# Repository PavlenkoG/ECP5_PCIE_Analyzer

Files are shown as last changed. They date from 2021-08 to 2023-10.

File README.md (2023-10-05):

# ECP5_PCIE_Analyzer
The main idea of this project is the evaluation of the possibility of using the PCS-Block of ECP5UMG FPGA for PCI-Express protocol analysis.
The PCS Block can deserialize physical PCI-Express signals and decode 8b10b. <p>
Deserialized data can be used to analyze protocol traffic, detecting errors and so on.<p>
The first implementation involves an adapter print to connect PCI-Express lanes to PCS-Block in FPGA and an evaluation board with ECP5UM(G).<p>
The adapter print should be connected to the eval. board through VERSA Expansion headers and SMA-Cables.

https://www.latticesemi.com/products/developmentboardsandkits/ecp5evaluationboard
# VERSA Expansion Headers
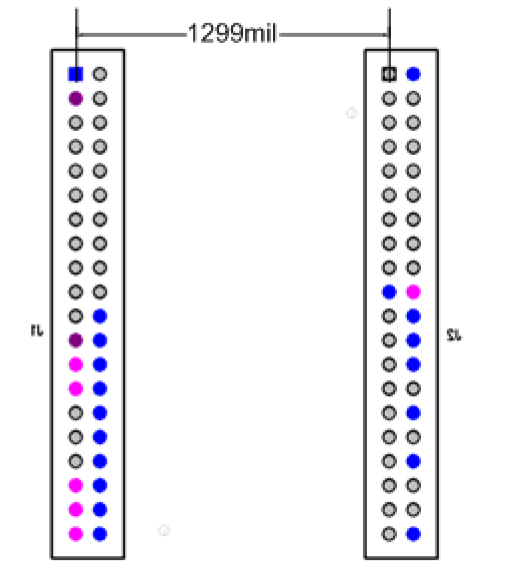
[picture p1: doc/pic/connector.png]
sch

# Eval Board top view
Block Schema

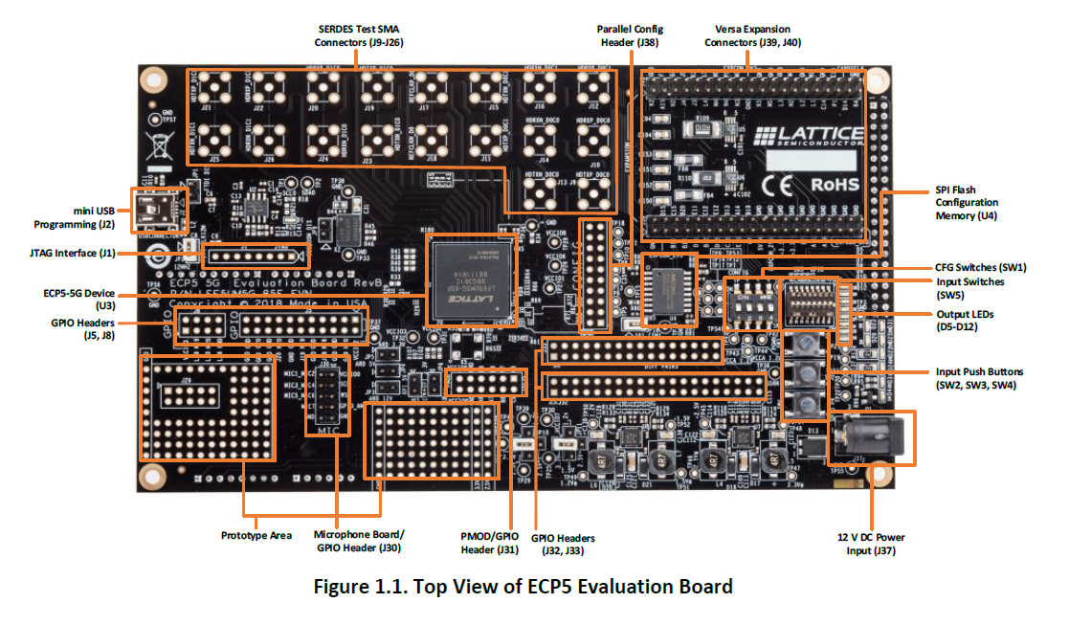
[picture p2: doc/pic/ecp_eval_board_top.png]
Eval Board Top


# Eval Board bottom view
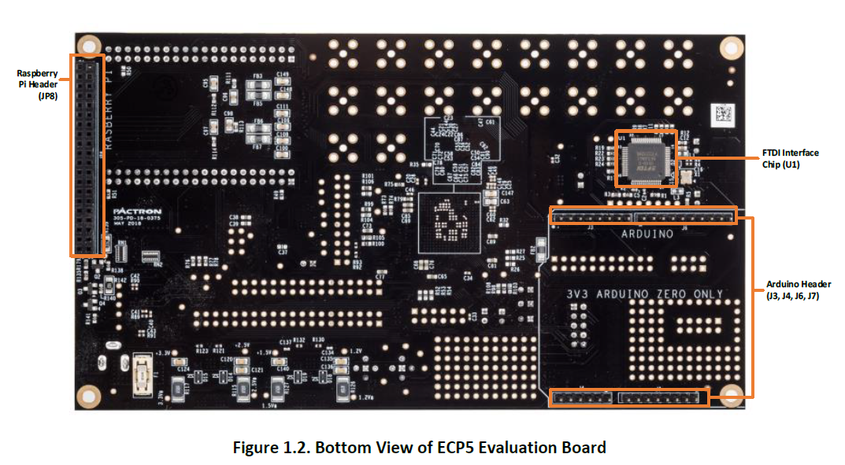
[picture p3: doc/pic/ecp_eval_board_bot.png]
Eval Board Bottom


# PCB

Preparing for applying solder paste
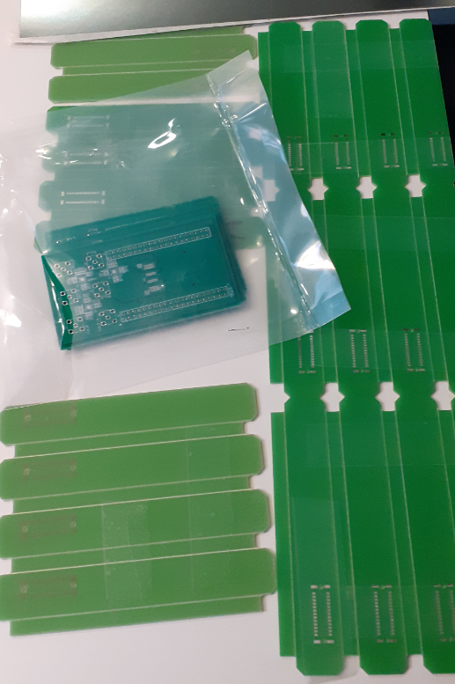
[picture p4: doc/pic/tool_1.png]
tool_1


Mounting of SMT Stencil
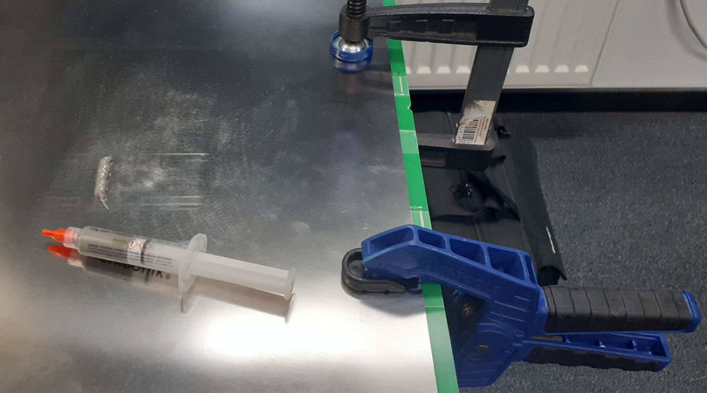
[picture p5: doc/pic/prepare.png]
mounting of SMT Stencil


Applying solder paste
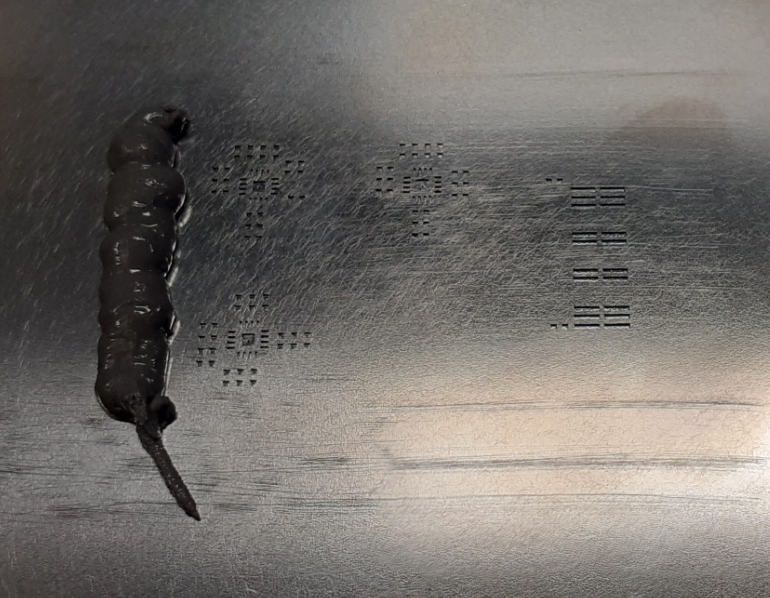
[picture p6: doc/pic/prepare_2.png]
applying solder paste


PCB
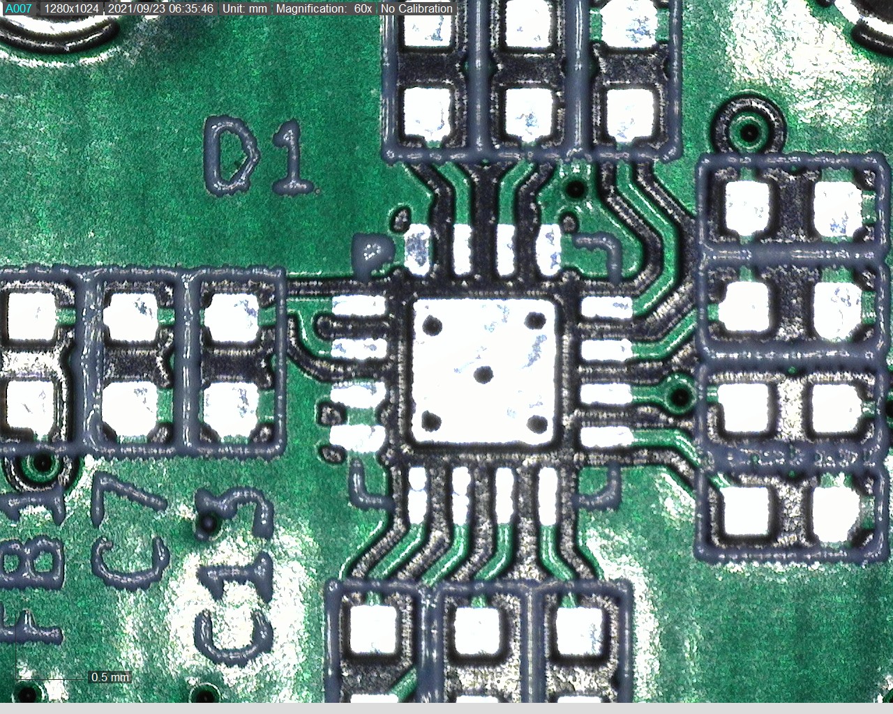
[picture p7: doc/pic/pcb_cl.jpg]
PCB


PCB with solder paste
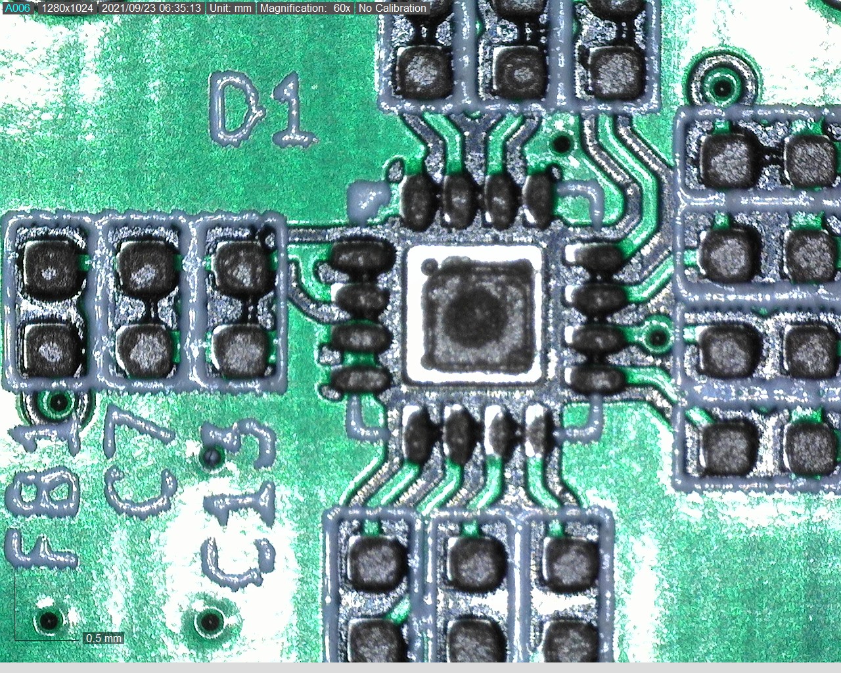
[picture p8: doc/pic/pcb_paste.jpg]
PCB with paste


Mounted PCB
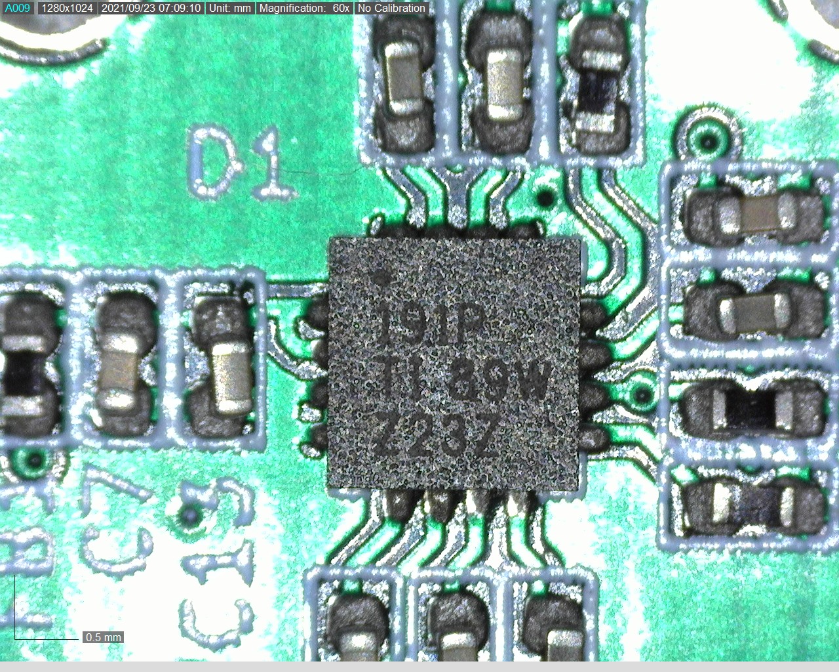
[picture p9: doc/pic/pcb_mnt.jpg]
Mounted PCB


# Python script usage

## record data (on raspberry pi)

```
pi@raspberrypi:~/github/ECP5_PCIE_Analyzer/py_script $ python3 analyzer.py
['analyzer.py']
file removed
Time:  11.82167429399999 s
```

## analyze data

copy data to local
```
scp -r pi@192.168.178.29:~/github/ECP5_PCIE_Analyzer/py_script/*.csv .
```

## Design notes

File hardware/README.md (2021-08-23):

## Impedance calculation JLCPCB

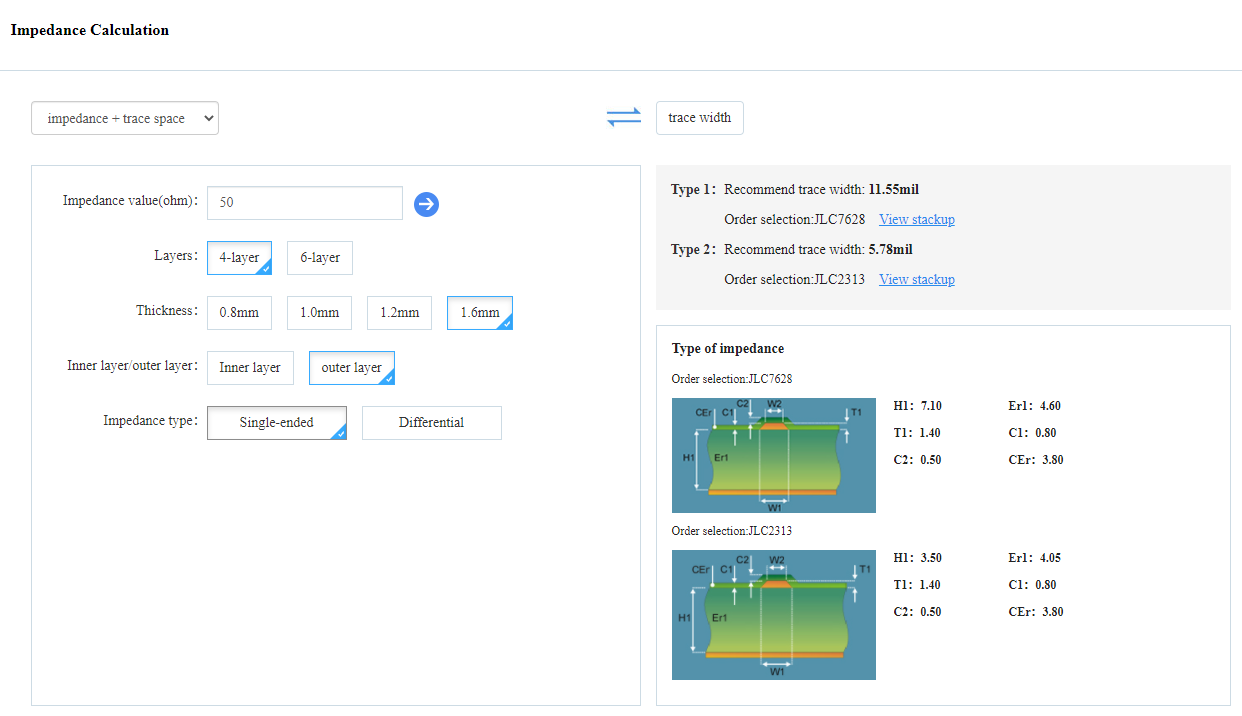
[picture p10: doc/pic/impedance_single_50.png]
impedance 50 Ohm single

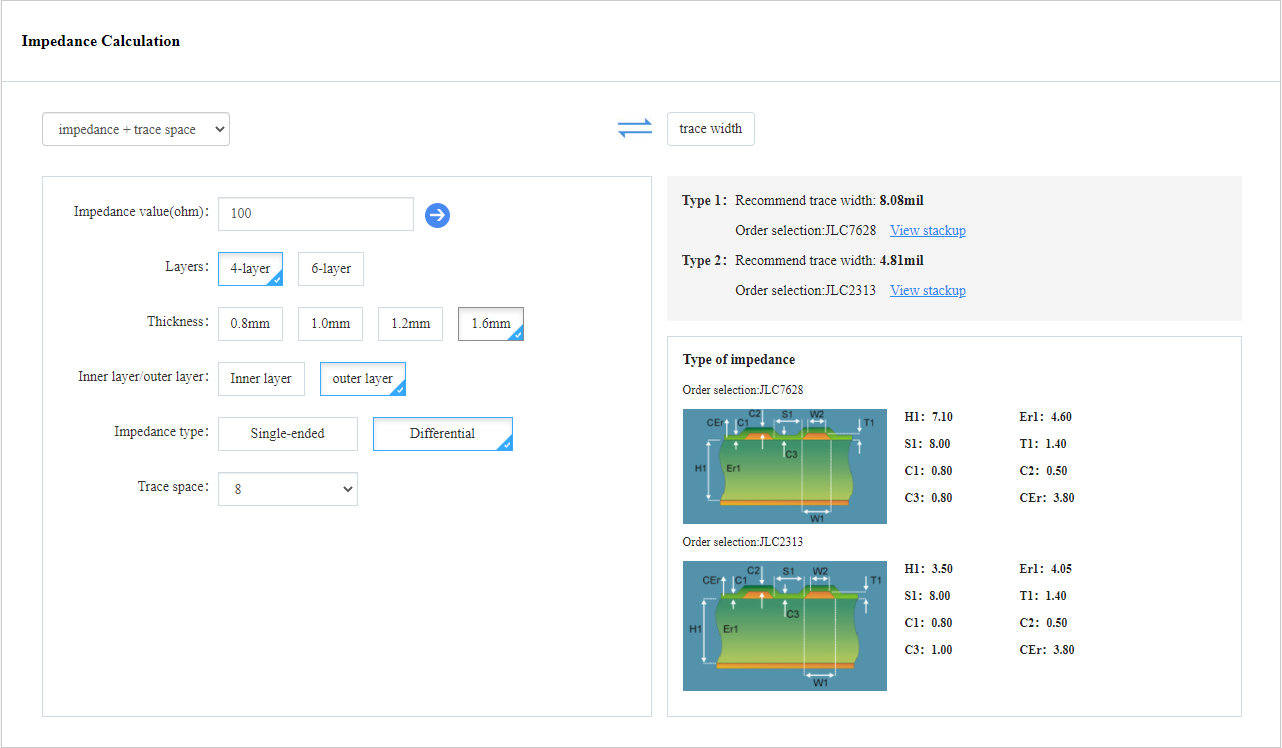
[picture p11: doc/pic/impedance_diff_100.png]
impedance 100 Ohm diff


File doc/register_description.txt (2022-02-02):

config_reg
    7   - reset
    1   - stop_trigger
    0   - start_trig
status_reg_0
    7
    6
    5
    4   - rxstatus1_1
    3   - rxstatus1_0
    2   - rxstatus0_1
    1   - rxstatus0_0
    0   - trig_run
status_reg_1
    7
    6
    5   - los_1
    4   - los_0
    3   - rx_cdr_lol_s_1
    2   - rx_cdr_lol_s_0
    1   - lsm_status_1
    0   - lsm_status_0
config_tlp
    0   - filter tlp
config_dllp
    0   - filter dllp
config_ordset
    0   - filter ordset

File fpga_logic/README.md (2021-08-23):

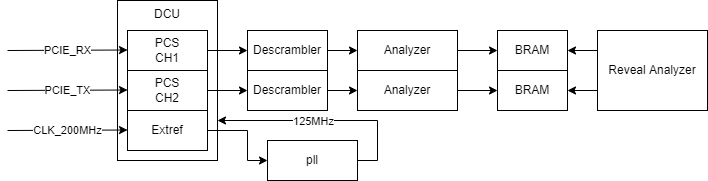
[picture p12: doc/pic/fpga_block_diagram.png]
Block Schema


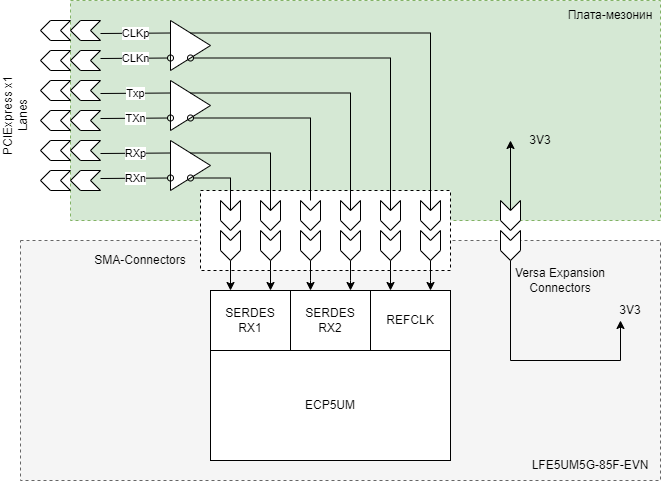
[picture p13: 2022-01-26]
doc/pic/analyzer_block_diagram.png

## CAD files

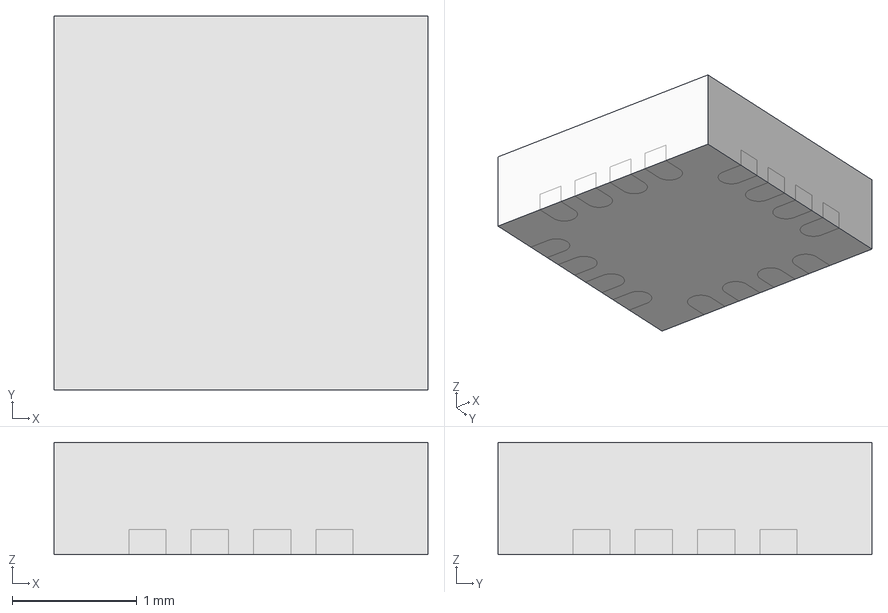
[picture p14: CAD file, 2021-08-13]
3D_Freecad/vson.FCStd
3.00 x 3.00 x 0.9 mm

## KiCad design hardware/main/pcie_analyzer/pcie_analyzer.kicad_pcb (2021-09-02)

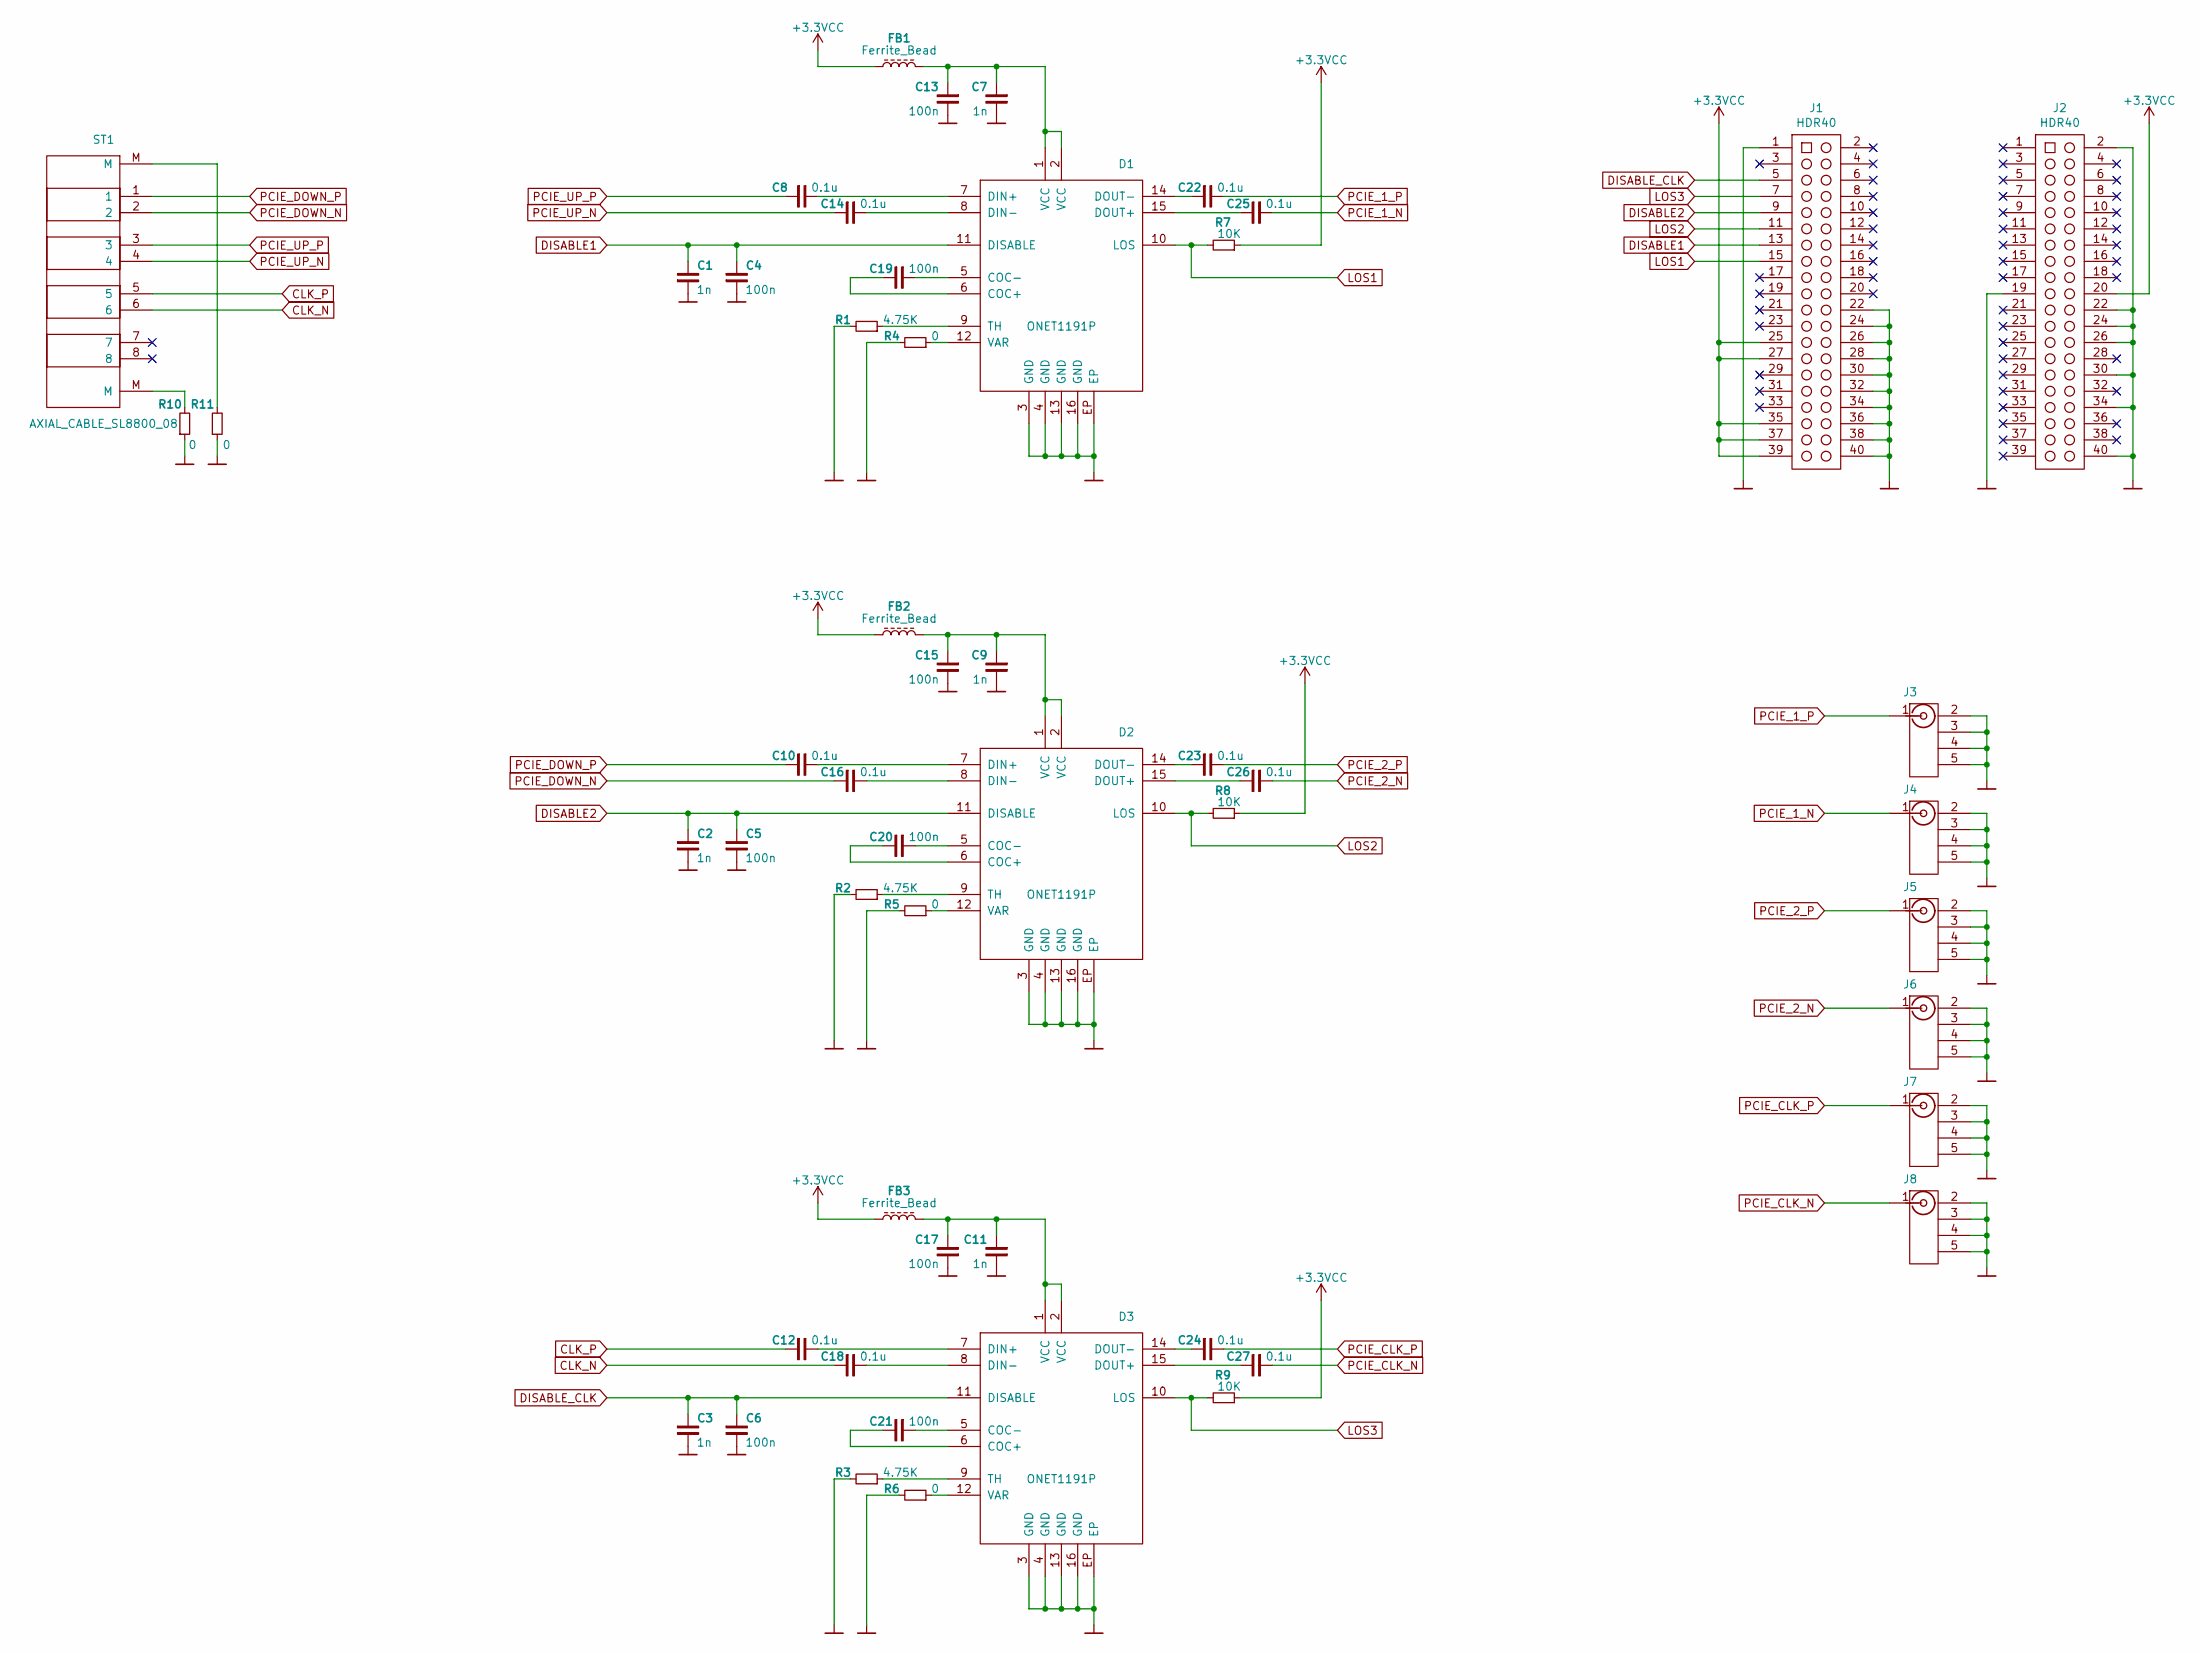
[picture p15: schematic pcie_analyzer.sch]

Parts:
C1, C2, C3, C7, C9, C11: 1n; C_0402
C4, C5, C6, C13, C15, C17, C19, C20, C21: 100n; C_0402
C8, C10, C12, C14, C16, C18, C22, C23, C24, C25, C26, C27: 0.1u; C_0402
D1, D2, D3: ONET1191P; VQFN-16
FB1, FB2, FB3: Ferrite_Bead; FB_0402
J1, J2: HDR40; SAMTEC_TSW-120-05-G-D
J3, J4, J5, J6, J7, J8: Conn_Coaxial; SMA_Amphenol_132291_Vertical
R1, R2, R3: 4.75K; R_0402
R4, R5, R6, R10, R11: 0; R_0402
R7, R8, R9: 10K; R_0402
ST1: AXIAL_CABLE_SL8800_08

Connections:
+3.3VCC: FB1.2, FB2.2, FB3.2, J1.25, J1.27, J1.35, J1.37, J1.39, J2.20, R7.2, R8.2, R9.2
CLK_N: C18.2, ST1.6
CLK_P: C12.2, ST1.5
DISABLE1: C1.1, C4.1, D1.11 (DISABLE), J1.13
DISABLE2: C2.1, C5.1, D2.11 (DISABLE), J1.9
DISABLE_CLK: C3.1, C6.1, D3.11 (DISABLE), J1.5
GND: C1.2, C2.2, C3.2, C4.2, C5.2, C6.2, C7.2, C9.2, C11.2, C13.2, C15.2, C17.2, D1.3 (GND), D1.4 (GND), D1.13 (GND), D1.16 (GND), D1.EP, D2.3 (GND), D2.4 (GND), D2.13 (GND), D2.16 (GND), D2.EP, D3.3 (GND), D3.4 (GND), D3.13 (GND), D3.16 (GND), D3.EP, J1.1, J1.22, J1.24, J1.26, J1.28, J1.30, J1.32, J1.34, J1.36, J1.38, J1.40, J2.2, J2.19, J2.22, J2.24, J2.26, J2.30, J2.34, J2.40, J3.2 (Ext), J3.3, J3.4, J3.5, J4.2 (Ext), J4.3, J4.4, J4.5, J5.2 (Ext), J5.3, J5.4, J5.5, J6.2 (Ext), J6.3, J6.4, J6.5, J7.2 (Ext), J7.3, J7.4, J7.5, J8.2 (Ext), J8.3, J8.4, J8.5, R1.1, R2.1, R3.1, R4.1, R5.1, R6.1, R10.2, R11.2
LOS1: D1.10 (LOS), J1.15, R7.1
LOS2: D2.10 (LOS), J1.11, R8.1
LOS3: D3.10 (LOS), J1.7, R9.1
unnamed: C8.1, D1.7 (DIN+)
unnamed: C10.1, D2.7 (DIN+)
unnamed: C11.1, C17.1, D3.1 (VCC), D3.2 (VCC), FB3.1
unnamed: C12.1, D3.7 (DIN+)
unnamed: C7.1, C13.1, D1.1 (VCC), D1.2 (VCC), FB1.1
unnamed: C14.1, D1.8 (DIN-)
unnamed: C9.1, C15.1, D2.1 (VCC), D2.2 (VCC), FB2.1
unnamed: C16.1, D2.8 (DIN-)
unnamed: C18.1, D3.8 (DIN-)
unnamed: C19.1, D1.5 (COC-)
unnamed: C19.2, D1.6 (COC+)
unnamed: C20.1, D2.5 (COC-)
unnamed: C20.2, D2.6 (COC+)
unnamed: C21.1, D3.5 (COC-)
unnamed: C21.2, D3.6 (COC+)
unnamed: C22.2, D1.14 (DOUT-)
unnamed: C23.2, D2.14 (DOUT-)
unnamed: C24.2, D3.14 (DOUT-)
unnamed: C25.2, D1.15 (DOUT+)
unnamed: C26.2, D2.15 (DOUT+)
unnamed: C27.2, D3.15 (DOUT+)
unnamed: D1.9 (TH), R1.2
unnamed: D1.12 (VAR), R4.2
unnamed: D2.9 (TH), R2.2
unnamed: D2.12 (VAR), R5.2
unnamed: D3.9 (TH), R3.2
unnamed: D3.12 (VAR), R6.2
unnamed: R10.1, ST1.M, ST1.M2
unnamed: R11.1, ST1.M, ST1.M1
PCIE_1_N: C25.1, J4.1 (In)
PCIE_1_P: C22.1, J3.1 (In)
PCIE_2_N: C26.1, J6.1 (In)
PCIE_2_P: C23.1, J5.1 (In)
PCIE_CLK_N: C27.1, J8.1 (In)
PCIE_CLK_P: C24.1, J7.1 (In)
PCIE_DOWN_N: C16.2, ST1.2
PCIE_DOWN_P: C10.2, ST1.1
PCIE_UP_N: C14.2, ST1.4
PCIE_UP_P: C8.2, ST1.3

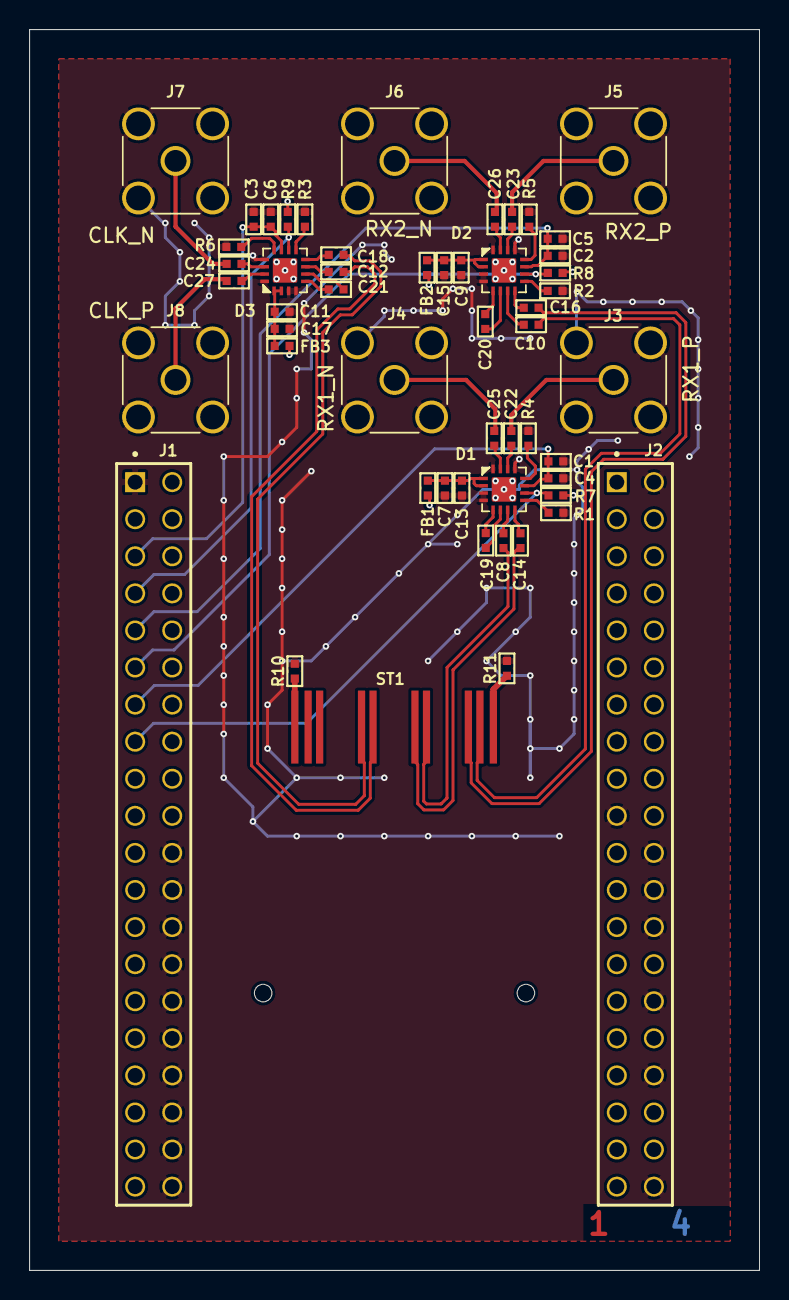
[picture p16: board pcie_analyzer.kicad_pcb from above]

Board: 4 copper layers, 50.0 x 85.0 mm, 53 parts (0 on the bottom side), 49 nets.

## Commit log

2021-08-06 create KiCad project
    [pcie_analyzer.kicad_pcb, pcie_analyzer.sch]
2021-08-06 added op_amp to sch
    [pcie_analyzer.sch]
2021-08-06 vunit, sch work
    [pcie_analyzer.sch]
2021-08-08 schema update
    [pcie_analyzer.sch]
2021-08-12 schema update, opAmp replaced with ONET1191P
    [pcie_analyzer.sch]
2021-08-12 VQFN case added to library
2021-08-12 first annotat schematics,
    [pcie_analyzer.sch]
2021-08-12 pcb added
    [pcie_analyzer.kicad_pcb]
2021-08-13 shema error correction
    [pcie_analyzer.sch]
2021-08-13 placement components
    [pcie_analyzer.kicad_pcb]
2021-08-13 vqfn 3d shape added
    [vson.FCStd]
2021-08-16 pcie twin axial cable added
2021-08-16 pcb work
    [pcie_analyzer.kicad_pcb, pcie_analyzer.sch]
2021-08-17 daily work
    [pcie_analyzer.kicad_pcb, pcie_analyzer.sch]
2021-08-19 axial cable sym and pcb update
2021-08-19 first release sch/pcb
    [pcie_analyzer.kicad_pcb, pcie_analyzer.sch]
2021-08-26 spi slave added
2021-09-02 assembly plan updated
    [pcie_analyzer.kicad_pcb]
2021-10-07 major design update
    [pcie_analyzer.sch]
2022-01-26 tlp filter update
2022-01-31 ECP5UM-45caBGA381 symbol added to KiCad library
2022-01-31 daily work, spi controller, tb update
2022-02-01 remove reveal analyzer, implement spi controller
2022-02-01 constraints - pin 25 mhz input corrected
2022-02-04 init mem to spi test on hardware
2022-02-04 spi freq as variable
2022-02-09 spi read addr error corrected
